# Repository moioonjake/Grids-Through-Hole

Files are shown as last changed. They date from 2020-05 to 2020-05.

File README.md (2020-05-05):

# Grids Through-Hole aka Ruudukko

Grids through-hole is a through-hole adaptation of the Mutable Instruments Grids Topographic drum sequencer. It’s a 100% non-commercial effort developed purely for own educational purposes where I’m trying to learn to understand schematics, Kicad and PCB making.

As recommended I have changed the name on the PCB's, "Ruudukko" means Grids in Finnish.

Please note that this is not yet tested or verified (2020-05), I’d like to hear your feedback if you built this module so I can improve these files.

# Design
The original SMD PCB is all-in-one but since there's no space for THT components and keep the original control layout (Control board) I added secondary PCB for the "Brains" (Brains board). Basically this can be built without the Control board if you use wires from Brains board (from PINS(1-3).1 outputs) to output jacks, switch and potentiometers. Note that there's couple resistors and leds on the Control board so without the Control board add these to the jacks and switches.
<br><br>I also added those two bonus outs (clock and random gates) to the Control board upper right corner, these are optional like in the original. Also wire connect points to MIDI is moved to the Brains board, this requires wires to MIDI connector or add stereo 3.5mm jack and wire MIDI from Brains board to that.
<br><br>PCB's were made in Kicad and in the same board file and then separated.

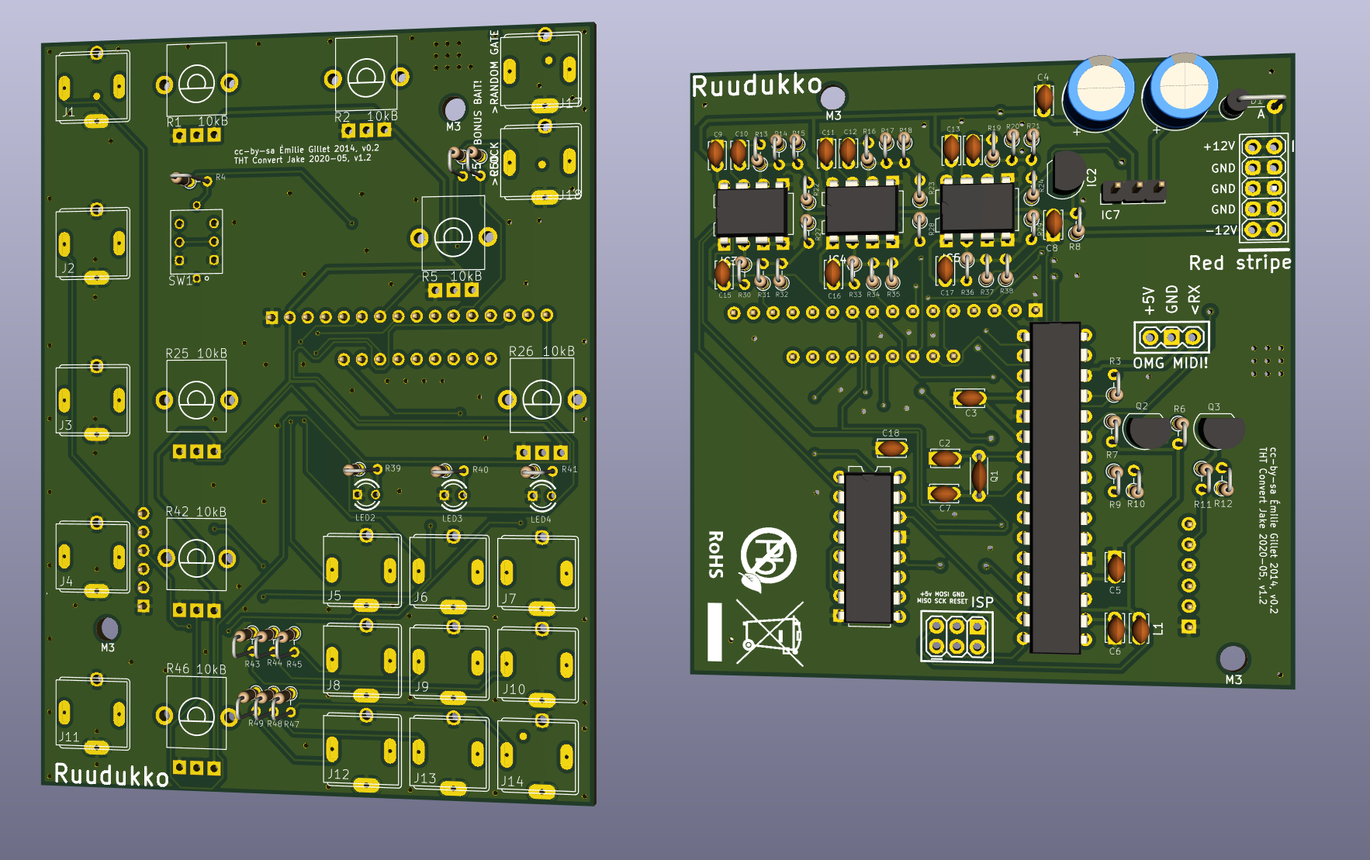
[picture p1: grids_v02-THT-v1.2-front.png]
image of THT-v1.1 front side


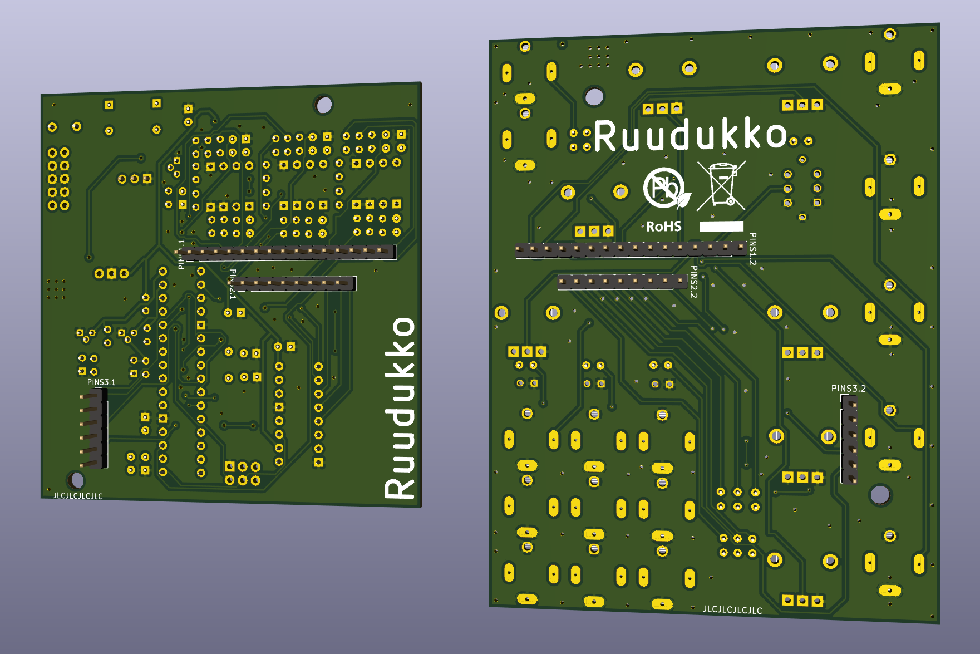
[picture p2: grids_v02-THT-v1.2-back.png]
image of THT-v1.1 back side


Brains board:<br>
width : 74.93 mm<br>
height : 78.11 mm

Control board:<br>
width : 78.08 mm<br>
height : 102.87 mm

I'm going to do second Control board with thonkiconn jacks and board height under 100mm. The minus side on that is the original layout will be lost so with that Control board the original panel is not matching anymore and that board require different panel. So if you're going to make own panel then it does not matter.

Schematic is original, but I added two bonus outputs and resistors (v1.2), I did not add PINS(1-3).(1-2) to the schematic, only to the boards.

# Version History
v1.2
- Added resistors to two bonus outputs
  - Schema update
  - Control PCB update
  
v1.1
- Original release

# Panel
Original should work fine as the Control board layout as kept as original, if you want to use the bonus outs drill two holes to the panel upper right corner for jacks.

Link to the original panel files: https://github.com/pichenettes/eurorack/tree/master/grids/hardware_design/panel

# Possible updates
- Add: MIDI output to stereo 3.5mm jack to Control board. On the PINS3.(1-2) GND can be changed so that MIDI would be transported via PINS3.(1-2) pin6 between boards. Add stereo 3.5mm jack to Control board and wire TIP to the PINS3.2 pin6 and on the Brains board wire MIDI RX to PINS3.1 pin6.

# Notes
Original files, code & BOM can be found here: https://github.com/pichenettes/eurorack/tree/master/grids
<br>Note that BOM needs convert from SMD to THT components.

# License
Hardware: cc-by-sa-3.0

# Disclaimer of liability
The material and information contained on this website is for general information purposes only. You should not rely upon the material or information on the website as a basis for making any business, legal or any other decisions.
Whilst I endeavour to keep the information up to date and correct, I make no representations or warranties of any kind, express or implied about the completeness, accuracy, reliability, suitability or availability with respect to the website or the information, products, services or related graphics contained on the website for any purpose. Any reliance you place on such material is therefore strictly at your own risk.

I will not be liable for any false, inaccurate, inappropriate or incomplete information presented on the website.

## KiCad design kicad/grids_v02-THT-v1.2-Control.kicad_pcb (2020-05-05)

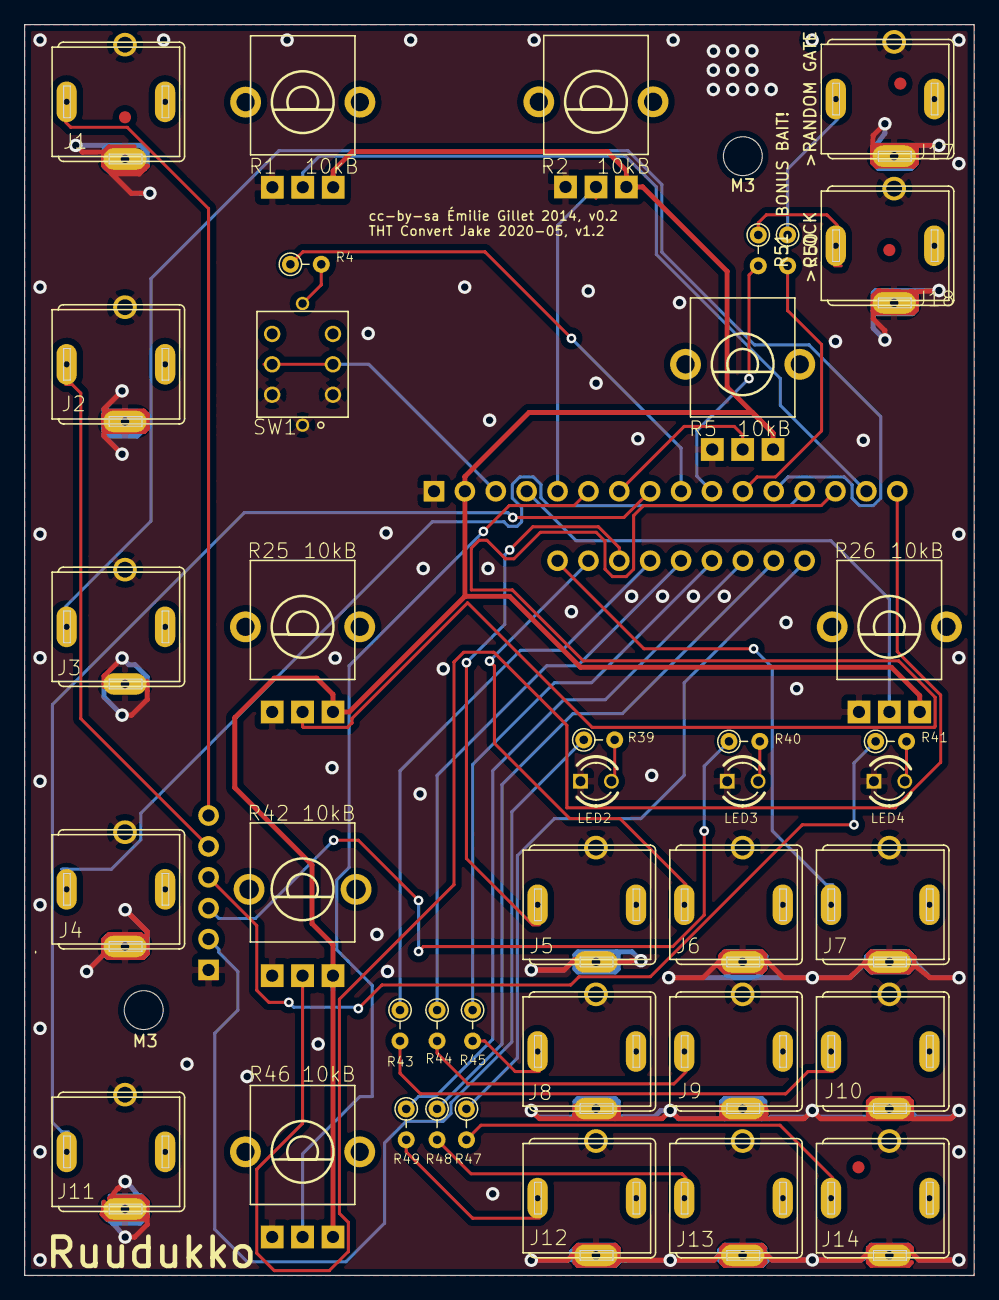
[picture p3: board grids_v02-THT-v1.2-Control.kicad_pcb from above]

Board: 2 copper layers, 78.1 x 102.9 mm, 50 parts (0 on the bottom side), 42 nets.

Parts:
F1, F2, F3, F4: FIDUCIAL1X2; FIDUCIAL-1X2
J1, J2, J3, J4, J5, J6, J7, J8, J9, J10, J11, J12, J13, J14, J17, J18: PJ301WQP; WQP_PJ_301BM
LED2, LED3, LED4: LED3MM
M3, M3#2: MountingHole_3.2mm_M3
PINS1.2: PinHeader_1x16_P2.54mm_Vertical
PINS2.2: PinHeader_1x09_P2.54mm_Vertical
PINS3.2: PinHeader_1x06_P2.54mm_Vertical
R1, R2, R5, R25, R26, R46: 10kB; ALPS_POT_VERTICAL_PS
R4, R39, R40, R41: 100; R_Axial_DIN0204_L3.6mm_D1.6mm_P2.54mm_Vertical
R42: 10kB; ALPS_POT_VERTICAL_PS4
R43, R44, R45, R47, R48, R49, R50, R51: 1.0k; R_Axial_DIN0204_L3.6mm_D1.6mm_P2.54mm_Vertical
SW1: LP4OA1PBCT
U$1: EURORACK_TEMPLATE
U$2: ROHS_BIG

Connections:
+5V: PINS1.2.2, R1.P$1, R2.P$1, R5.P$1, R25.P$1, R26.P$1, R42.P$1, R46.P$1
/LED_CH1: PINS3.2.5, R39.1
/LED_CH2: PINS3.2.4, R40.1
/LED_CH3: PINS3.2.3, R41.1
/LED_CLOCK: PINS1.2.9, R4.1
/SW_RESET: PINS1.2.3, SW1.P2, SW1.P5
/TEMPO: PINS1.2.15, R1.P$2
GND: J1.GND, J1.GND2, J2.GND, J2.GND2, J3.GND, J3.GND2, J4.GND, J4.GND2, J5.GND, J5.GND2, J6.GND, J6.GND2, J7.GND, J7.GND2, J8.GND, J8.GND2, J9.GND, J9.GND2, J10.GND, J10.GND2, J11.GND, J11.GND2, J12.GND, J12.GND2, J13.GND, J13.GND2, J14.GND, J14.GND2, J17.GND, J17.GND2, J18.GND, J18.GND2, LED2.K, LED3.K, LED4.K, PINS1.2.1, PINS3.2.6, R1.P$3, R2.P$3, R5.P$3, R25.P$3, R26.P$3, R42.P$3, R46.P$3, SW1.L2, SW1.P3, SW1.P6
unnamed: PINS2.2.5, R44.1
unnamed: PINS2.2.4, R43.1
unnamed: PINS2.2.7, R49.1
unnamed: PINS2.2.8, R48.1
unnamed: PINS2.2.9, R47.1
unnamed: PINS1.2.10, R51.2
unnamed: PINS1.2.11, R50.2
unnamed: PINS2.2.6, R45.1
unnamed: J1.TIP, PINS3.2.1
unnamed: J2.TIP, PINS3.2.2
unnamed: J3.TIP, PINS1.2.12
unnamed: J4.TIP, PINS1.2.13
unnamed: J5.TIP, PINS2.2.3
unnamed: J6.TIP, PINS2.2.2
unnamed: J7.TIP, PINS2.2.1
unnamed: J8.TIP, R45.2
unnamed: J9.TIP, R44.2
unnamed: J10.TIP, R43.2
unnamed: J11.TIP, PINS1.2.8
unnamed: J12.TIP, R49.2
unnamed: J13.TIP, R48.2
unnamed: J14.TIP, R47.2
unnamed: J17.TIP, R50.1
unnamed: J18.TIP, R51.1
unnamed: LED2.A, R39.2
unnamed: LED3.A, R40.2
unnamed: LED4.A, R41.2
unnamed: R4.2, SW1.L1
unnamed: PINS1.2.16, R42.P$2
unnamed: PINS1.2.5, R2.P$2
unnamed: PINS1.2.4, R26.P$2
unnamed: PINS1.2.14, R25.P$2
unnamed: PINS1.2.6, R46.P$2
unnamed: PINS1.2.7, R5.P$2

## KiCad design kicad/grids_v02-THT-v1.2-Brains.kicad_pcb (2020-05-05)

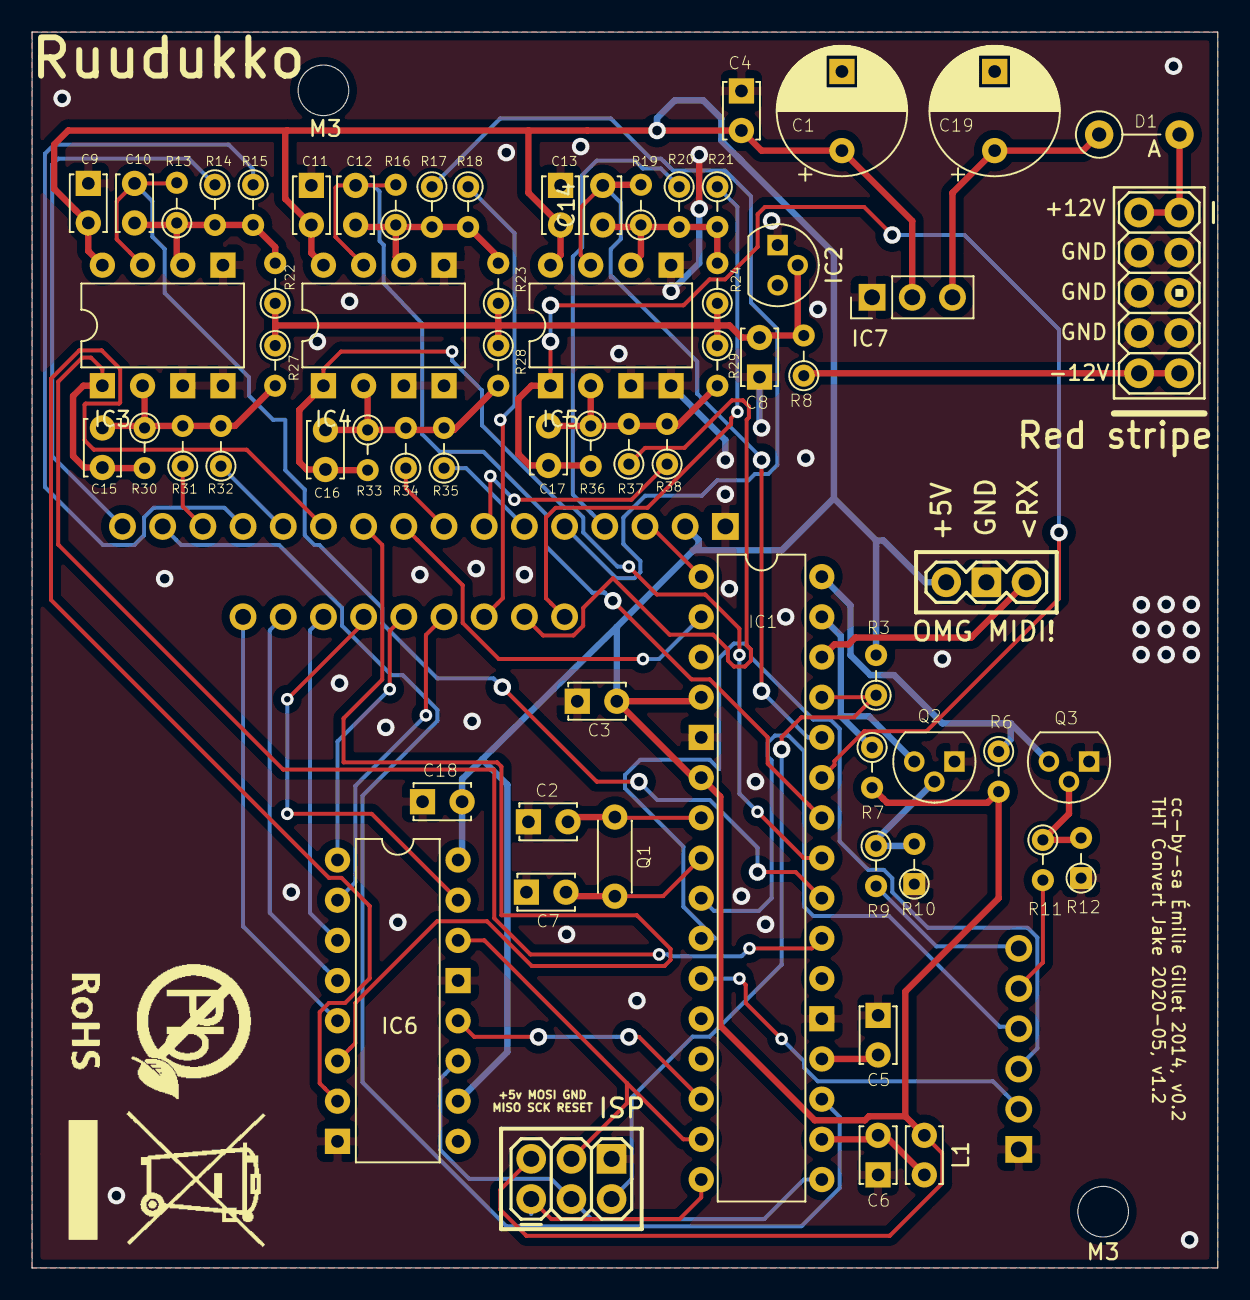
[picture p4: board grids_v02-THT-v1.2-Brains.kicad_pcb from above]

Board: 2 copper layers, 74.9 x 78.1 mm, 73 parts (0 on the bottom side), 60 nets.

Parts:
C1, C19: 22u; CP_Radial_D8.0mm_P5.00mm
C2, C7: 18p; C_Disc_D3.4mm_W2.1mm_P2.50mm
C3, C4, C5, C6, C9, C11, C13, C18: 100n; C_Disc_D3.4mm_W2.1mm_P2.50mm
C8: 470n; C_Disc_D3.4mm_W2.1mm_P2.50mm
C10, C12, C14, C15, C16, C17: 10n; C_Disc_D3.4mm_W2.1mm_P2.50mm
D1: 1N5819HW; D_A-405_P5.08mm_Vertical_AnodeUp
IC1: ATMEGA328P-AU; DIP-32_W7.62mm
IC2: LM4040 5.0V; TO-92
IC3, IC4, IC5: MCP6002; DIP-8_W7.62mm
IC6: 74595D; DIP-16_W7.62mm
IC7: LM1117-5.0; PinHeader_1x03_P2.54mm_Vertical
J15: AVR_SPI_PRG_6PTH; 2X3
J16: M05X2PTH; AVR_ICSP
JP2: M03PTH; 1X03
L1: WE-CBF_0603; C_Disc_D3.4mm_W2.1mm_P2.50mm
M3, M3#2: MountingHole_3.2mm_M3
PINS1.1: PinHeader_1x16_P2.54mm_Vertical
PINS2.1: PinHeader_1x09_P2.54mm_Vertical
PINS3.1: PinHeader_1x06_P2.54mm_Vertical
Q1: 20MHz; C_Disc_D4.3mm_W1.9mm_P5.00mm
Q2, Q3: MMBT3904; TO-92
R3, R6, R7, R8: 10k; R_Axial_DIN0204_L3.6mm_D1.6mm_P2.54mm_Vertical
R9, R11, R13, R14, R15, R16, R17, R18, R19, R20, R21, R22, R23, R24, R27, R28, R29, R30, R31, R32, R33, R34, R35, R36, R37, R38: 100k; R_Axial_DIN0204_L3.6mm_D1.6mm_P2.54mm_Vertical
R10, R12: 1M; R_Axial_DIN0204_L3.6mm_D1.6mm_P2.54mm_Vertical
U$1: EURORACK_TEMPLATE
U$2: ROHS_BIG

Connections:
+5V: C1.1, C3.1, C4.1, C9.1, C11.1, C13.1, C18.1, IC1.4, IC1.6, IC3.8, IC4.8, IC5.8, IC6.10, IC6.16, IC7.2, J15.2, JP2.3, L1.1, PINS1.1.2, R3.2, R6.2, R7.2
/AREF: C5.1, IC1.20
/CH1_CV: C12.2, IC1.26, IC4.7, R16.2
/CH2_CV: C17.2, IC1.27, IC5.1, R36.2
/CH3_CV: C14.2, IC1.28, IC5.7, R19.2
/IN_CLOCK: IC1.31, Q2.C, R7.1
/IN_MIDI: IC1.30, JP2.1
/IN_RESET: IC1.32, Q3.C, R6.1
/LED_CH1: IC1.11, PINS3.1.5
/LED_CH2: IC1.10, PINS3.1.4
/LED_CH3: IC1.9, PINS3.1.3
/LED_CLOCK: IC1.2, PINS1.1.9
/MISO: IC1.16, J15.1
/MOSI: IC1.15, IC6.14, J15.4
/REF_-5: C8.1, IC2.2, R8.2, R22.1, R23.1, R24.1, R27.1, R28.1, R29.1
/RESET: IC1.29, J15.5, R3.1
/RND_CV: C16.2, IC1.25, IC4.1, R33.2
/SCK: IC1.17, IC6.11, J15.3
/SS: IC1.14, IC6.12
/SW_RESET: IC1.1, PINS1.1.3
/TEMPO: IC1.19, PINS1.1.15
/X_CV: C15.2, IC1.23, IC3.1, R30.2
/Y_CV: C10.2, IC1.24, IC3.7, R13.2
GND: C2.1, C3.2, C4.2, C5.2, C6.2, C7.1, C8.2, C9.2, C11.2, C13.2, C18.2, IC1.3, IC1.5, IC1.21, IC2.1, IC3.3, IC3.4, IC3.5, IC4.3, IC4.4, IC4.5, IC5.3, IC5.4, IC5.5, IC6.8, IC6.13, IC7.1, J15.6, J16.3, J16.4, J16.5, J16.6, J16.7, J16.8, JP2.2, PINS1.1.1, PINS3.1.6, Q2.E, Q3.E, R10.1, R12.1
unnamed: C2.2, IC1.7, Q1.2
unnamed: C6.1, IC1.18, L1.2
unnamed: C7.2, IC1.8, Q1.1
unnamed: C10.1, IC3.6, R13.1, R14.2, R15.2, R22.2
unnamed: C12.1, IC4.6, R16.1, R17.2, R18.2, R23.2
unnamed: C14.1, IC5.6, R19.1, R20.2, R21.2, R24.2
unnamed: C15.1, IC3.2, R27.2, R30.1, R31.2, R32.2
unnamed: C16.1, IC4.2, R28.2, R33.1, R34.2, R35.2
unnamed: C17.1, IC5.2, R29.2, R36.1, R37.2, R38.2
unnamed: D1.2, J16.9, J16.10
unnamed: IC6.1, PINS2.1.5
unnamed: IC6.2, PINS2.1.4
unnamed: IC6.3, PINS2.1.7
unnamed: IC6.4, PINS2.1.8
unnamed: IC6.5, PINS2.1.9
unnamed: IC6.6, PINS1.1.10
unnamed: IC6.7, PINS1.1.11
unnamed: IC6.15, PINS2.1.6
unnamed: PINS3.1.1, R9.2
unnamed: PINS3.1.2, R11.2
unnamed: PINS1.1.12, R32.1
unnamed: PINS1.1.13, R15.1
unnamed: PINS2.1.3, R18.1
unnamed: PINS2.1.2, R37.1
unnamed: PINS2.1.1, R21.1
unnamed: PINS1.1.8, R34.1
unnamed: Q2.B, R9.1, R10.2
unnamed: Q3.B, R11.1, R12.2
unnamed: PINS1.1.16, R14.1
unnamed: PINS1.1.5, R17.1
unnamed: PINS1.1.4, R20.1
unnamed: PINS1.1.14, R31.1
unnamed: PINS1.1.6, R35.1
unnamed: PINS1.1.7, R38.1
VCC: C19.1, D1.1, IC7.3
VEE: J16.1, J16.2, R8.1

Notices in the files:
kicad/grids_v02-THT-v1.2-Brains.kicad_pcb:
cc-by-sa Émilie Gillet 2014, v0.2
